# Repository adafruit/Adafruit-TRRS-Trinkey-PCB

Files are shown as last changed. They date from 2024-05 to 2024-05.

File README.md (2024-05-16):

## Adafruit TRRS Trinkey - USB Key for Assistive Technology PCB

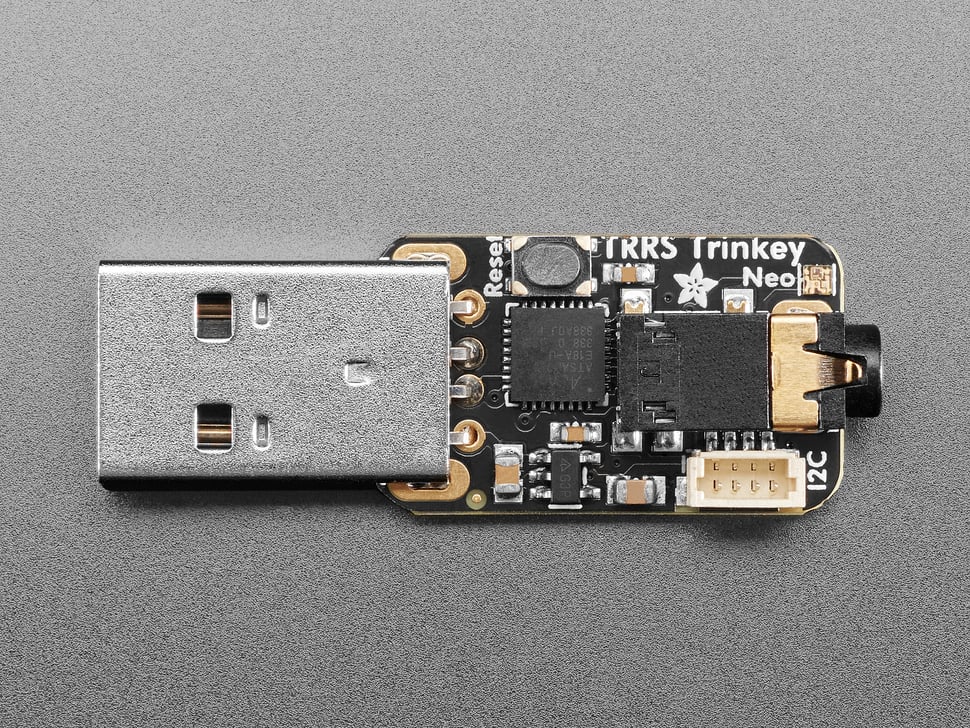
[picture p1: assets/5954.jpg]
<a href="http://www.adafruit.com/products/5954"><br/>
Click here to purchase one from the Adafruit shop</a>

PCB files for the Adafruit TRRS Trinkey - USB Key for Assistive Technology. 

Format is EagleCAD schematic and board layout
* https://www.adafruit.com/product/5954

### Description

It's half USB Key, half TRRS breakout... it's the Adafruit TRRS Trinkey specifically designed for Assistive Technology hackers and creators as a simple and low cost, but also flexible and extendable AT device. 

Many AT interface devices use 3.5mm audio jacks to create switches or variable inputs - often mono TS or stereo TRS plugs. On the TRRS Trinkey, we connect all 6 pins of a 'switched' TRRS jack - tip, ring 1, ring 2, sleeve and the tip switch plus ring 1 switch - to 6 GPIO pins on the microcontroller. That means we can not only detect when plugs are inserted but can change which pins are input, ground or even 3V power. With the use of a stereo/mic splitter, we can have up to 3 simple switches, or two analog potentiometers, or one of each! We particularly like this jack because it has two through-hole contacts near the opening for a good mechanical connection.

The PCB is designed to plug into any USB A port on a computer or laptop. There's an ATSAMD21 microcontroller on board with just enough circuitry to keep it happy. One pin of the microcontroller connects to a NeoPixel LED. A reset button lets you enter bootloader mode if necessary. The microcontroller can be programmed easily thanks to the UF2 bootloader and CircuitPython: simply drag-n-drop new code on.

The SAMD21 can run CircuitPython or Arduino nicely. Over the USB connection, you can have serial, MIDI, or HID keyboard/mouse connectivity. Because its a fully programmable chip, it's possible to customize the keyboard or mouse commands executed on each button, or even set up chording patterns.

Features:

* ATSAMD21E18 32-bit Cortex M0+ - 48 MHz 32-bit processor with 256KB Flash and 32 KB RAM
* Native USB supported by every OS - can be used in Arduino or CircuitPython as a USB serial console, MIDI, Keyboard/Mouse HID, and even a little disk drive for storing Python scripts. Can act like a keyboard to phones or tablets with a USB adapter cable.
* Can be used with Arduino IDE or CircuitPython
* TRRS Jack with two switches on tip and ring 1. All 6 contacts connect to analog-input capable GPIO pins
* One RGB NeoPixel LED
* STEMMA QT port with JST SH 4-pin compatible connector - can be used to add I2C devices, or two more inputs. Note CircuitPython may not have enough memory for large chip drivers.
* Reset switch to start your project code over or enter bootloader mode
* Open Source Hardware so you have full control over your assistive tech!

### License

Adafruit invests time and resources providing this open source design, please support Adafruit and open-source hardware by purchasing products from [Adafruit](https://www.adafruit.com)!

Designed by Limor Fried/Ladyada for Adafruit Industries.

Creative Commons Attribution/Share-Alike, all text above must be included in any redistribution. 
See license.txt for additional details.

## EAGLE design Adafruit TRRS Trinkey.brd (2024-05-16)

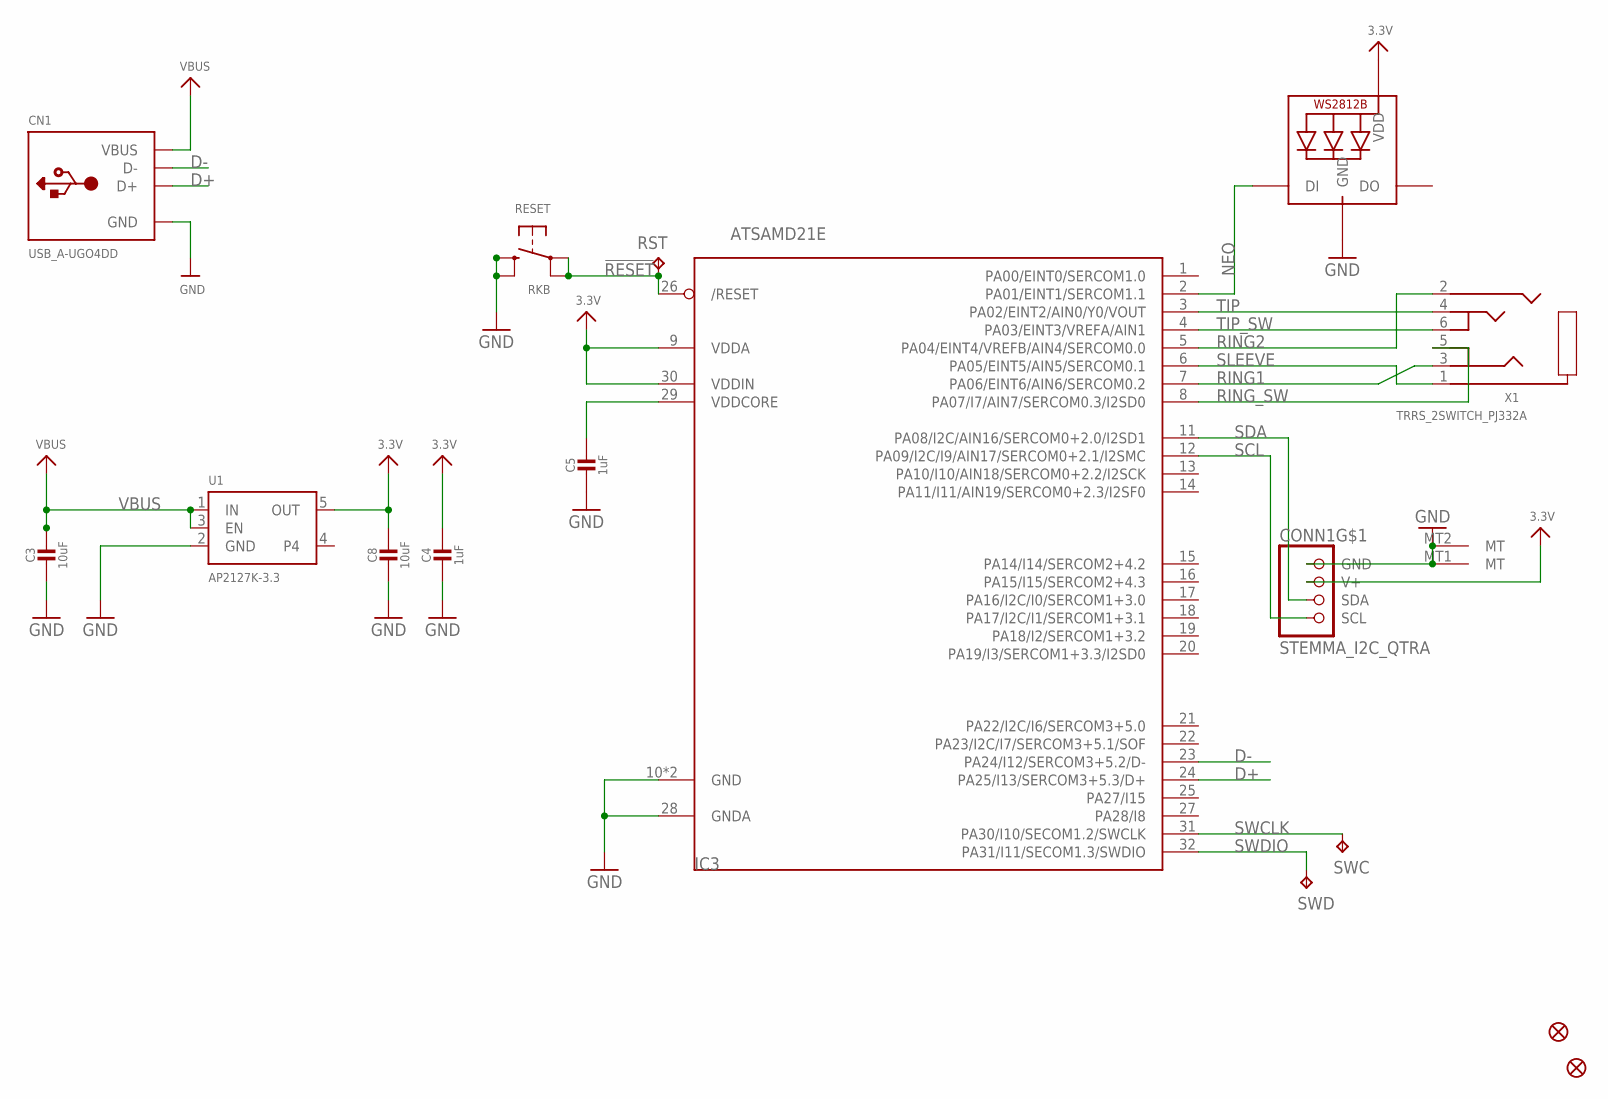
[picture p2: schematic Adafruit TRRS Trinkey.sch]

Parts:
C3, C8: 10uF; 0805-NO
C4, C5: 1uF; 0603-NO
CN1: USB_A-UGO4DD
CONN1: STEMMA_I2C_QTRA; JST_SH4_RA
FID1, FID2: FIDUCIAL_0.5MM
IC3: ATSAMD21E; QFN32_5MM
LED1: WS2812B_SK6805_1515; SK6805_1515
RESET: RKB; BTN_RKB2_4.6X2.8
RST: TPTP16R; TP16R
SWC: TPTP15R; TP15R
SWD: TPTP16R; TP16R
U1: AP2127K-3.3; SOT23-5; JLC_ROTATION 0
X1: TRRS_2SWITCH_PJ332A; PJ-332A

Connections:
3.3V: C4.1, C8.1, CONN1.2 (V+), IC3.9 (VDDA), IC3.30 (VDDIN), LED1.2 (VDD), U1.5 (OUT)
!RESET: IC3.26 (/RESET), RESET.A, RESET.A' (P1), RST.TP
D+: CN1.D+, IC3.24 (PA25/I13/SERCOM3+5.3/D+)
D-: CN1.D-, IC3.23 (PA24/I12/SERCOM3+5.2/D-)
GND: C3.2, C4.2, C5.2, C8.2, CN1.GND, CONN1.1 (GND), CONN1.MT1 (MT), CONN1.MT2 (MT), IC3.10 (GND), IC3.28 (GNDA), IC3.33 (GND), LED1.4 (GND), RESET.B (S), RESET.B' (S1), U1.2 (GND)
NEO: IC3.2 (PA01/EINT1/SERCOM1.1), LED1.1 (DI)
RING1: IC3.7 (PA06/EINT6/AIN6/SERCOM0.2), X1.3 (RING2)
RING2: IC3.5 (PA04/EINT4/VREFB/AIN4/SERCOM0.0), X1.2 (RING1)
RING_SW: IC3.8 (PA07/I7/AIN7/SERCOM0.3/I2SD0), X1.5 (R2_SW)
SCL: CONN1.4 (SCL), IC3.12 (PA09/I2C/I9/AIN17/SERCOM0+2.1/I2SMC)
SDA: CONN1.3 (SDA), IC3.11 (PA08/I2C/AIN16/SERCOM0+2.0/I2SD1)
SLEEVE: IC3.6 (PA05/EINT5/AIN5/SERCOM0.1), X1.1 (RING)
SWCLK: IC3.31 (PA30/I10/SECOM1.2/SWCLK), SWC.TP
SWDIO: IC3.32 (PA31/I11/SECOM1.3/SWDIO), SWD.TP
TIP: IC3.3 (PA02/EINT2/AIN0/Y0/VOUT), X1.4 (TIP)
TIP_SW: IC3.4 (PA03/EINT3/VREFA/AIN1), X1.6 (TIP_SW)
VBUS: C3.1, CN1.VBUS, U1.1 (IN), U1.3 (EN)
VDDCORE1: C5.1, IC3.29 (VDDCORE)

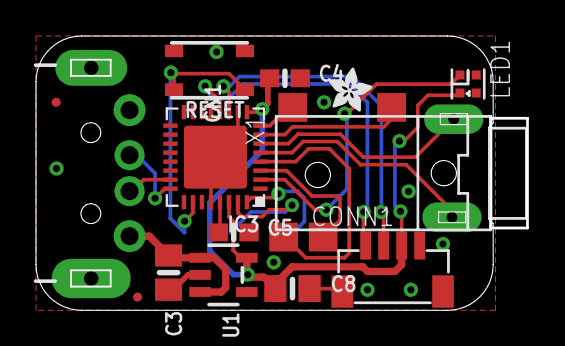
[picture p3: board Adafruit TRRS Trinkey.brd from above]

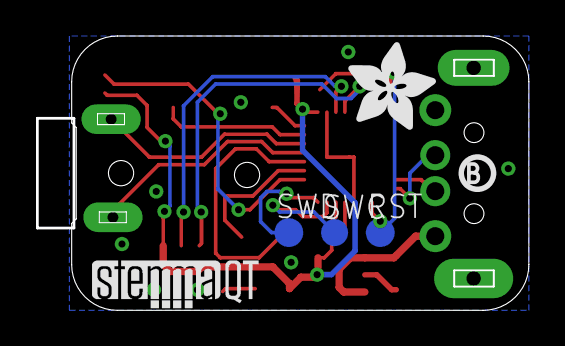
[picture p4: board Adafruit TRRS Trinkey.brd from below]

Board: 2 copper layers, 27.3 x 15.2 mm, 28 parts (10 on the bottom side), 18 nets.

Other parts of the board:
PLABEL4: PLABEL4
PLABEL5: PLABEL5
PLABEL6: PLABEL6
PLABEL9: PLABEL9
PLABEL10: PLABEL10
PLABEL11: PLABEL11
PLABEL12: PLABEL12
PLABEL13: PLABEL13
U$4: ADAFRUIT_2.5MM
U$5: STEMMAQT
U$7: ADAFRUIT_5MM
U$8: PCBFEAT-REV-040

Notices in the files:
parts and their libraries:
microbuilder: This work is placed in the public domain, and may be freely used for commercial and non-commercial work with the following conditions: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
